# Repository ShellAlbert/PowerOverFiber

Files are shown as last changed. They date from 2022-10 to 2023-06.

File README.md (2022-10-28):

# PowerOverFiber
Video Monitor Low Power Consumption Project   
TinyUARTCamera - STM32L496RGT6 LQFP-64   
SerialCamera - STM32L496ZGT6 LQFP-144    

# October 25, 2022   
InfraredCamera - iRay Infrared Camera LVCMOS 14-bits Gray image output.   
STM32L496ZGT6 LQFP-144 + PSRAM 32Mbits   
For single infrared image, the size is 640*512*16bits=5Mbits.    
STM32 FSMC Memory mapping    
Bank1: 4*64Mbyte    
Since we use CE1 in design, so the address range is 0x6000,0000~0x603F,FFFF   

We have IS66WVE2M16EBLL-70BLI-TR PSRAM on board, it has 21 bits address and 16 bits data bus, so 2^21*16bits=32Mbits.

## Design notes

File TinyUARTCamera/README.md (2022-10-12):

# TinyUARTCamera
MCU: STM32L496RGT6   
Camera: OV2640   
IDE: STM32CubeIDE_1.10.1 + STM32CubeL4 FW 1.17.2

First working version 
October 12, 2022 by Shell Albert   

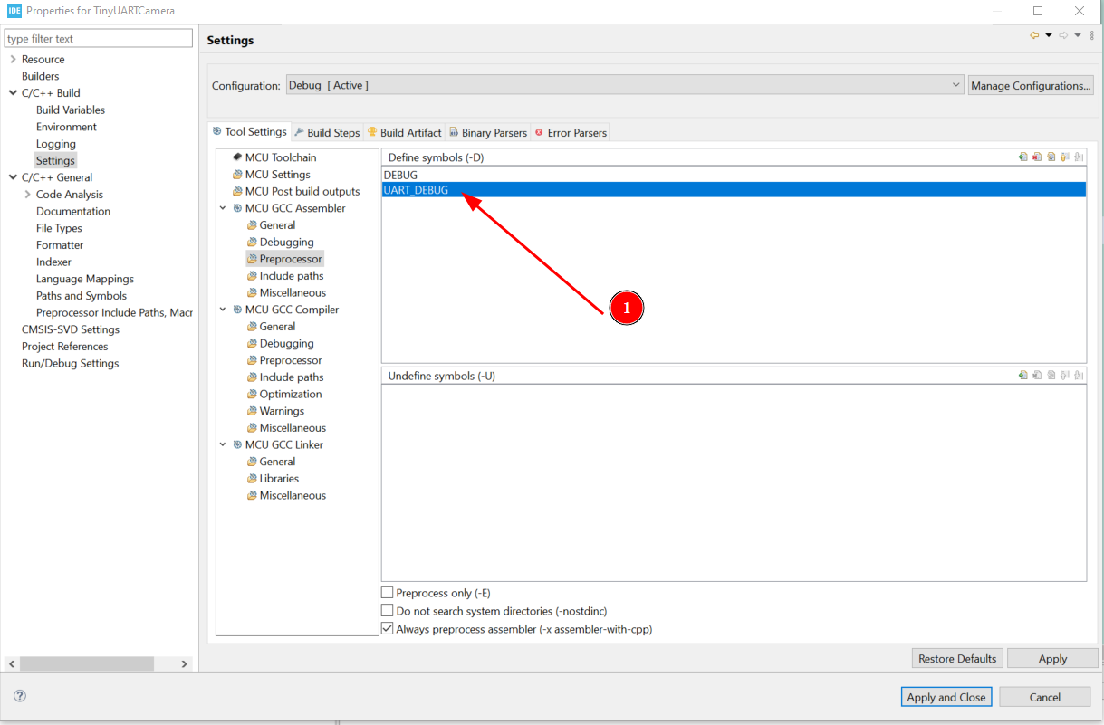
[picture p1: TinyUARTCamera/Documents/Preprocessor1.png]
Preprocessor1
   
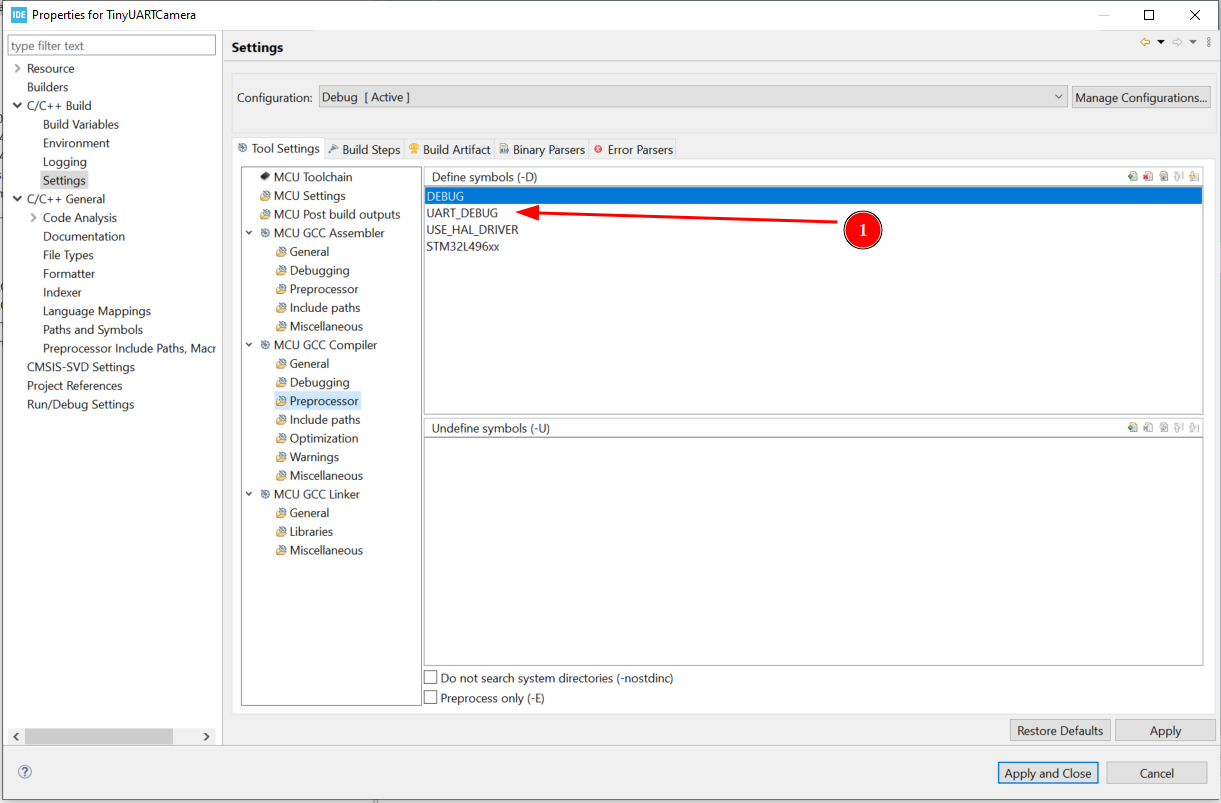
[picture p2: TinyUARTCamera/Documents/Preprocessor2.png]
Preprocessor2
   
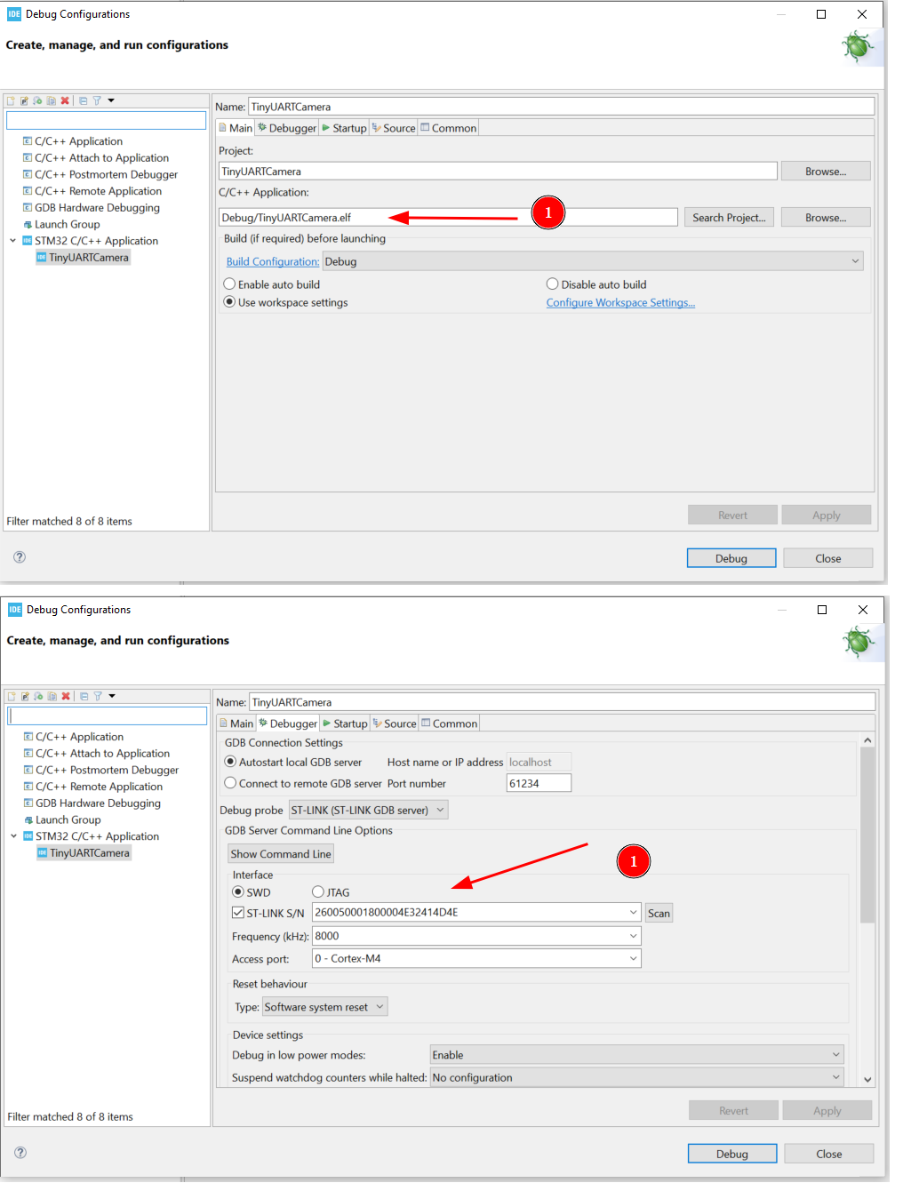
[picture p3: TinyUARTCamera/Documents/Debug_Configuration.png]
Debug_Configuration
   
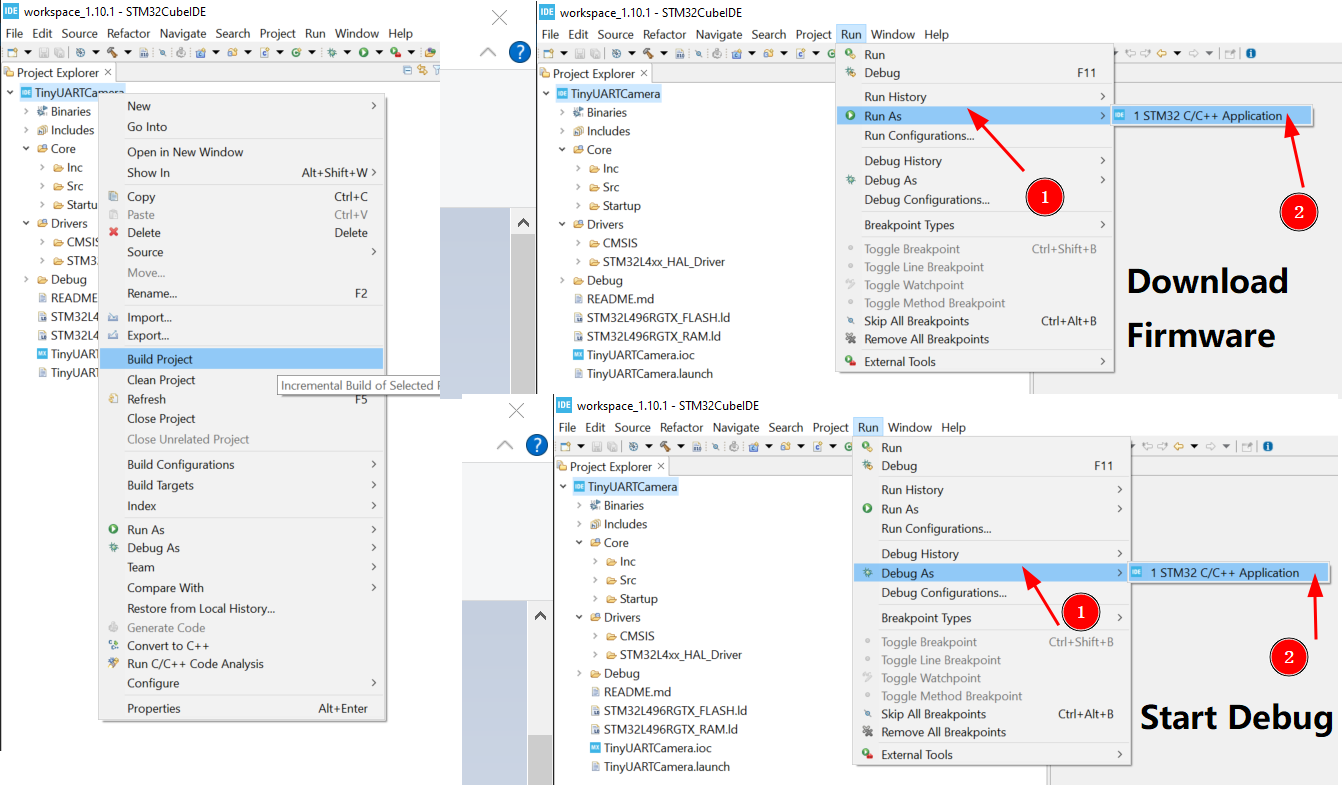
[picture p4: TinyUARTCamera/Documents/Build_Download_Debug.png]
Build_Download_Debug
   
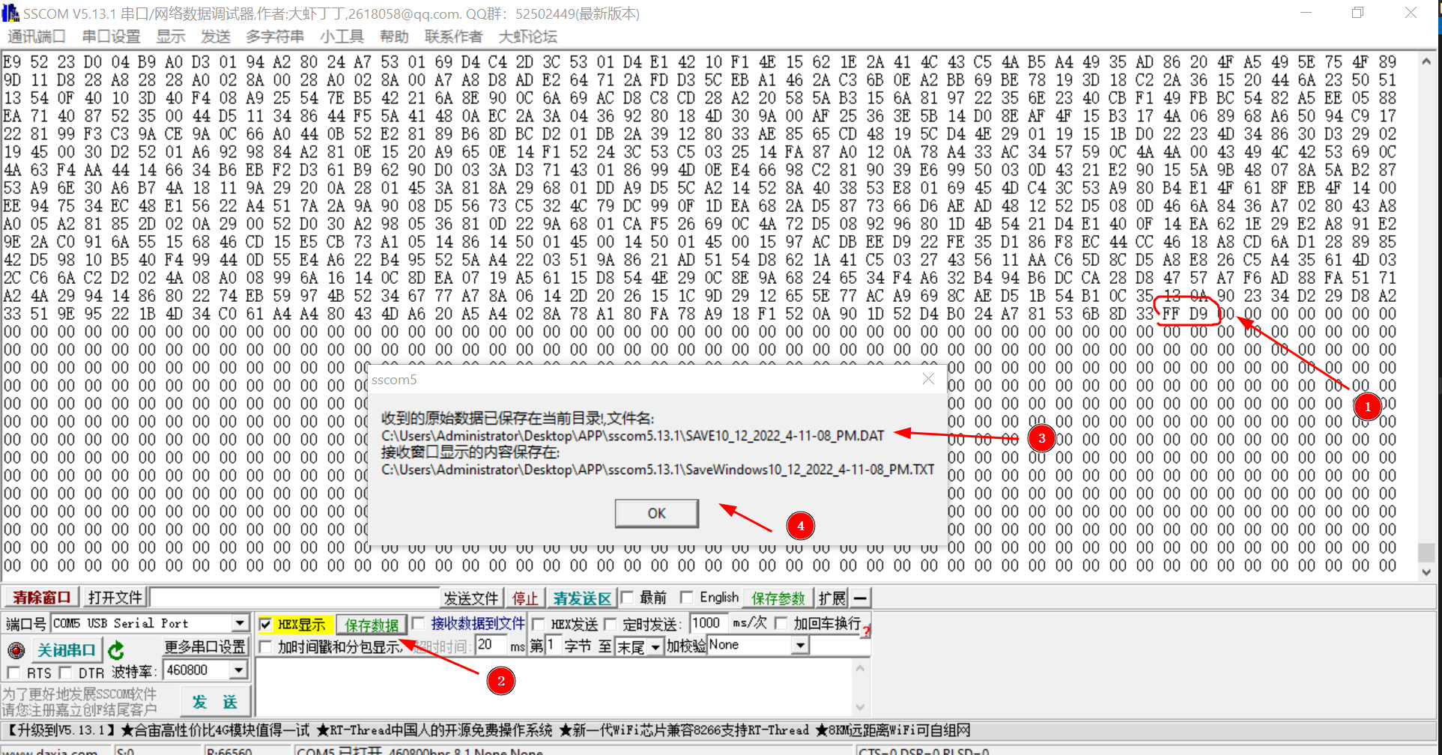
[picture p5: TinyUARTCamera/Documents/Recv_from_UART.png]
Recv_From_UART
   
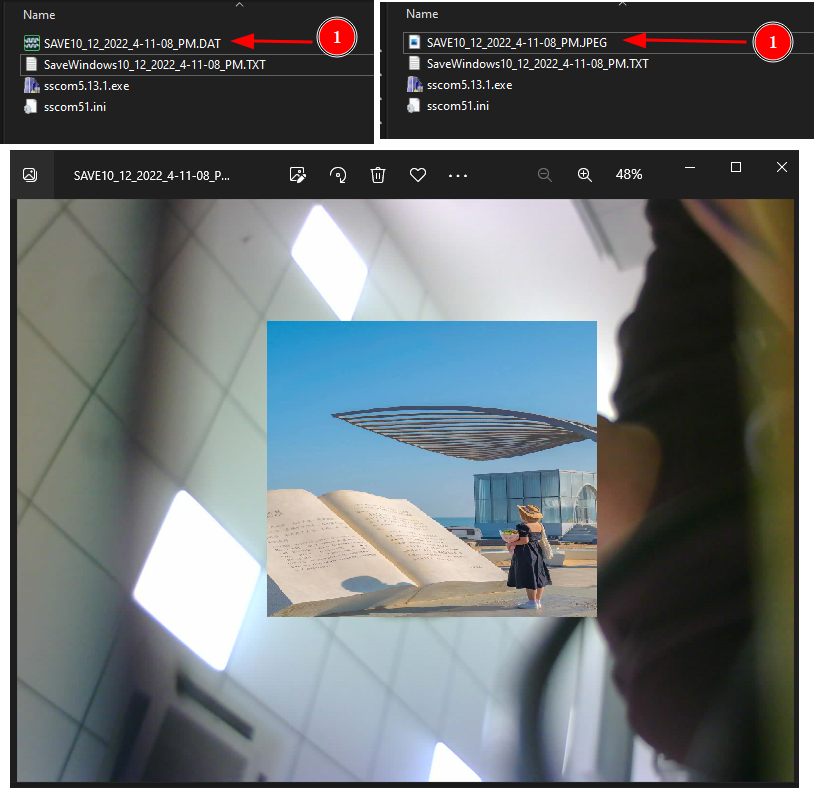
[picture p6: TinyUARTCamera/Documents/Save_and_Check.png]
Save_and_Check


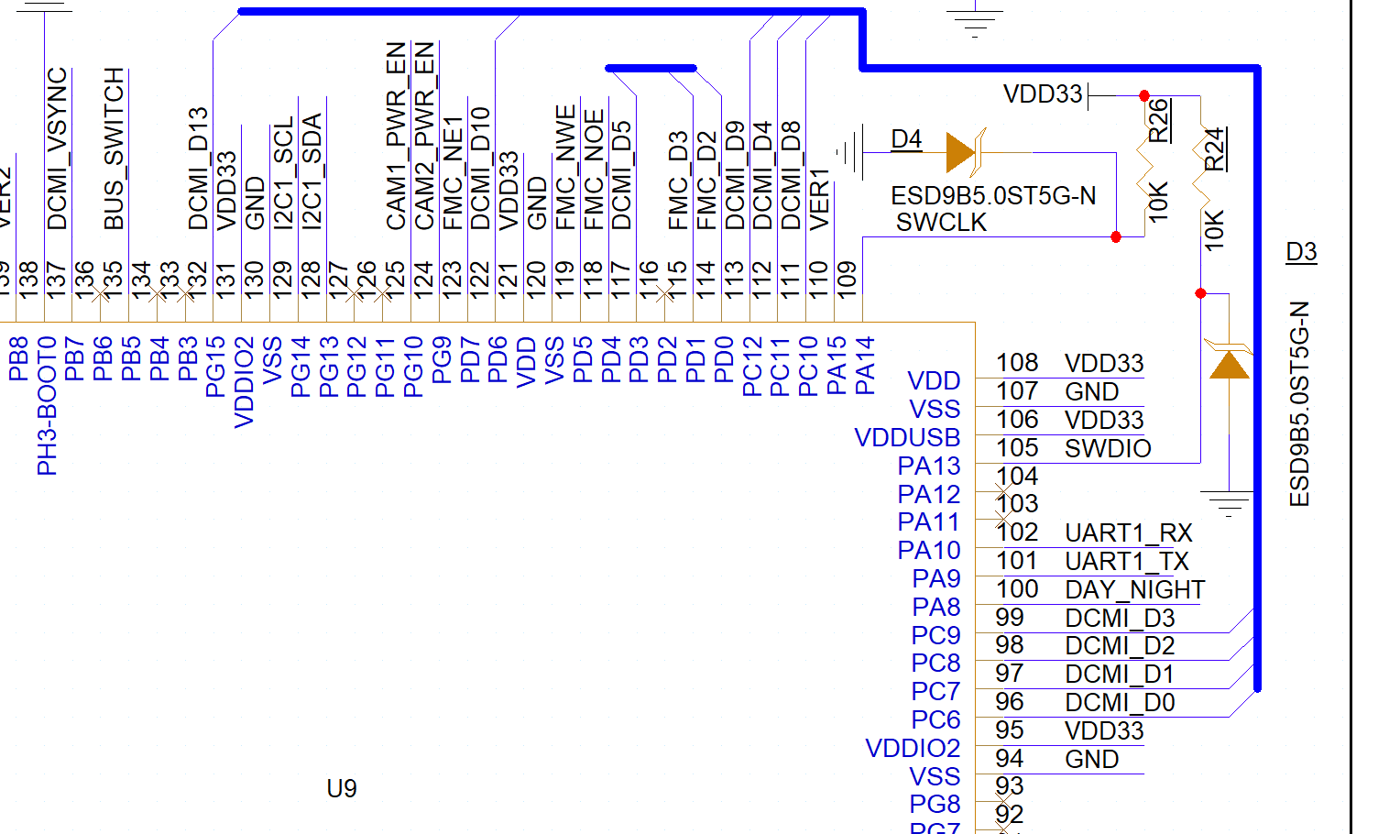
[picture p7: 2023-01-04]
Schematic/SERIALCAMERA.png

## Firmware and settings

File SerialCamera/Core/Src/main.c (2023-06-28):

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
/* Includes ------------------------------------------------------------------*/
#include "main.h"

/* USER CODE BEGIN Includes */
#include <string.h>
#include <stdio.h>
#include <stdarg.h>
#include "ov2640.h"
#include "Zsy_iRaySensor.h"
/* USER CODE END Includes */

/* USER CODE BEGIN PTD */
//#define ZDBG_MSG_EN 1
/* USER CODE END PTD */

DCMI_HandleTypeDef hdcmi;
DMA_HandleTypeDef hdma_dcmi;

I2C_HandleTypeDef hi2c1;
I2C_HandleTypeDef hi2c2;

TIM_HandleTypeDef htim1;

UART_HandleTypeDef huart1;
UART_HandleTypeDef huart2;
UART_HandleTypeDef huart3;

SRAM_HandleTypeDef hsram1;

/* USER CODE BEGIN PV */
static void
MX_DCMI_Init_OV2640 (void);
/* USER CODE END PV */

void SystemClock_Config(void);
static void MX_GPIO_Init(void);
static void MX_DMA_Init(void);
static void MX_DCMI_Init(void);
static void MX_I2C1_Init(void);
static void MX_I2C2_Init(void);
static void MX_TIM1_Init(void);
static void MX_USART1_UART_Init(void);
static void MX_USART2_UART_Init(void);
static void MX_USART3_UART_Init(void);
static void MX_FMC_Init(void);
/* USER CODE BEGIN PFP */
/* USER CODE BEGIN 0 */
/* USER CODE END PFP */


//the maximum linear address space is 65535 in word unit (32bits) for DMA.
//If the image size in words does not exceed 65535, the stream can be configured in normal mode.
//In general, one frame of JPEG compressed image can be 50KBytes~80KBytes.
//So here we use a 128KByte buffer.
#define JPEG_BUFFER_SIZE  (1024*31)  //128KB buffer size= 1024*31 INT bytes.
uint32_t iJpegBufferSize = JPEG_BUFFER_SIZE; //1024*128.
//SoC RAM.
//if we define this array as uint8_t, it will be failed. why?
//uint32_t iJpegBuffer[JPEG_BUFFER_SIZE];

//External RAM.
//Since DMA DONOT support write External RAM directly,
//so we must use DMA interrupt to copy data from SoC RAM to External RAM.
uint32_t iJpegBuffer[JPEG_BUFFER_SIZE] __attribute__ ((section(".ExtRAM")));
uint32_t iITFrameCnt = 0;
uint8_t g_iFSMFlag = 0;

/* frame buffer for infrared image buffer */
/* Yantai iRay Infrared Camera : 14-bit one pixel, resolution is 614*512 */
/* So 640*152*16bit/8bit= 655360bytes, /4bytes, sizeof(int)=163840 INT(32bits) */
/* 163840 Exceed 65535 !!!!!*/
#define INFRARED_IMGBUF_INT		163840 //(640*512*16/8/4)
uint32_t frameBufferExt[INFRARED_IMGBUF_INT] __attribute__ ((section(".ExtRAM")));

//SoC RAM Frame Buffer.
//640*512*16-bits
//640/2=320,512/2=256.
//The size of 1/4 part of image is calculated by 320*256*16-bits/8-bits=163840bytes,/4bytes=40960words.
#define SIZE_1_OF_4_WORD	(40960)
uint32_t frameBufferSoC[SIZE_1_OF_4_WORD + 128];

void
vprint (const char *fmt, va_list argp)
{
  char string[128];
  if (0 < vsprintf (string, fmt, argp)) // build string
    {
      // send message via UART3
      HAL_UART_Transmit (&huart3, (uint8_t*) string, strlen (string), 0xFFFF);
    }
}

void
ZUART_Printf (const char *fmt, ...) // custom printf() function
{
#ifdef ZDBG_MSG_EN
  va_list argp;
  va_start(argp, fmt);
  vprint (fmt, argp);
  va_end(argp);
#endif
}
/* USER CODE END 0 */

/**
  * @brief  The application entry point.
  * @retval int
  */
int main(void)
{
  /* USER CODE BEGIN 1 */
  char msg_buffer[128];
  uint32_t i;
  /* USER CODE END 1 */

  /* MCU Configuration--------------------------------------------------------*/

  /* Reset of all peripherals, Initializes the Flash interface and the Systick. */
  HAL_Init();

  /* Configure the system clock */
  SystemClock_Config();

  /* USER CODE BEGIN SysInit */

  //make sure MX_DCMI_Init() must be called after MX_DMA_Init().
  //make sure USART1_Init() must be called before GPIO_Init()
  //to avoid receive 00 at other side.
  /* USER CODE END SysInit */

  /* Initialize all configured peripherals */
  //MX_USART1_UART_Init();
  MX_USART2_UART_Init();
  //MX_USART3_UART_Init();
  MX_GPIO_Init();
  MX_DMA_Init();
  MX_DCMI_Init();
  MX_I2C1_Init();
  MX_I2C2_Init();
  //MX_TIM1_Init();
  //MX_FMC_Init();
  /* USER CODE BEGIN 2 */
  //ZUART_Printf("SerialCAM built on %s %s\r\n", __DATE__, __TIME__);
  /* External SRAM write-read test successfully!*/
#if 0
  //clear RAM to zero.
  for (i = 0; i < INFRARED_IMGBUF_INT; i++)
    {
      *(frameBufferExt + i) = 0;
    }
  //write data.
  for (i = 0; i < INFRARED_IMGBUF_INT; i++)
    {
      *(frameBufferExt + i) = i + 3;
    }
  //Read back and check data.
  for (i = 0; i < INFRARED_IMGBUF_INT; i++)
    {
      if ((i + 3) != frameBufferExt[i])
	{
	  sprintf (msg_buffer, "External RAM Test Error, %d!=%d, Code break down!\r\n", i + 3, frameBufferExt[i]);
	  HAL_UART_Transmit (&huart3, (uint8_t*) msg_buffer, strlen (msg_buffer), 200);
	  while (1)
	    {
	      //LED1 & LED2 OFF.
	      HAL_GPIO_WritePin (GPIOF, LED1_Pin | LED2_Pin, GPIO_PIN_RESET);
	      HAL_Delay (250);

	      //LED1 & LED2 ON.
	      HAL_GPIO_WritePin (GPIOF, LED1_Pin | LED2_Pin, GPIO_PIN_SET);
	      HAL_Delay (250);
	    }
	}
    }
#ifdef ZDBG_MSG_EN
  sprintf (msg_buffer, "External RAM Test Passed!\r\n");
  HAL_UART_Transmit (&huart3, (uint8_t*) msg_buffer, strlen (msg_buffer), 200);
#endif
#endif
  //Two LEDs OFF.
  HAL_GPIO_WritePin (GPIOF, LED1_Pin | LED2_Pin, GPIO_PIN_SET);

  //read DAY_NIGHT signal.
  //HAL_Delay (50);
  //if (HAL_GPIO_ReadPin (DAY_NIGHT_GPIO_Port, DAY_NIGHT_Pin))
  if (1)
    {
      //ZUART_Printf("Day - Visible\r\n");
      MX_DCMI_Init_OV2640 ();

      //Enable CAM1 power.
      HAL_GPIO_WritePin (GPIOG, CAM1_PWR_EN_Pin, GPIO_PIN_SET);
      //SYNC_SWITCH=0, CAM1 Signal Pass.
      //BUS_SWITCH=0, CAM1 Signal Pass.
      HAL_GPIO_WritePin (GPIOB, SYNC_SWITCH_Pin | BUS_SWITCH_Pin, GPIO_PIN_RESET);
      HAL_Delay (10);

      //Initial OV2640 registers via I2C.
      OV2640_Init (&hi2c1, &hdcmi);
      //must delay X seconds to bypass white-balance images to get normal images.
      HAL_Delay (3000);
      //OV2640_ResolutionOptions (imgRes);
      //HAL_Delay (10);

      /* Disable unwanted HSYNC (IT_LINE) / VSYNC (IT_VSYNC) interrupts */
      __HAL_DCMI_DISABLE_IT(&hdcmi, DCMI_IT_LINE | DCMI_IT_VSYNC|DCMI_IT_ERR|DCMI_IT_OVR);
      __HAL_DCMI_ENABLE_IT(&hdcmi, DCMI_IT_FRAME);

      while (1)
	{
	  uint8_t *pJpegData = (uint8_t*) (frameBufferSoC);
	  uint8_t iHeadFound = 0;
	  uint8_t iTailFound = 0;
	  uint32_t iValidEndPosition = 0;
	  int recv_len;
	  switch (g_iFSMFlag)
	    {
	    case 0:
	      //ZUART_Printf ("1-Start DMA\r\n");
	      //memset (frameBufferSoC, 0, SIZE_1_OF_4_WORD * 4);
	      //LED1 on.
	      //HAL_GPIO_WritePin (GPIOF, LED1_Pin, GPIO_PIN_RESET);
	      HAL_DCMI_Start_DMA (&hdcmi, DCMI_MODE_SNAPSHOT, (uint32_t) frameBufferSoC, SIZE_1_OF_4_WORD);
	      g_iFSMFlag = 1;
	      break;

	    case 1:
	      //ZUART_Printf("2-Waiting IT_FRAME...\r\n");
	      //HAL_Delay (100);
	      break;

	    case 2:
	      //ZUART_Printf("3-Get FRAME\r\n");
	      //Disable CAM1 power.
	      HAL_GPIO_WritePin (GPIOG, CAM1_PWR_EN_Pin, GPIO_PIN_RESET);
	      g_iFSMFlag = 3;
	      break;

	    case 3:
	      recv_len = SIZE_1_OF_4_WORD - __HAL_DMA_GET_COUNTER(hdcmi.DMA_Handle);
	      //ZUART_Printf("4-Get IT_FRAME %d,DMA %d\r\n", iITFrameCnt, recv_len);

	      //dump first 10 bytes data to UART3.
	      //ZUART_Printf("DATA-%08x-%08x\r\n", frameBufferSoC[0], frameBufferSoC[1]);

	      //frame head FF D8, frame end FF D9.
	      //loop to find the frame end to skip the last ZEROs.
	      for (i = 0; i < recv_len * 4; i++)
		{
		  if (pJpegData[i + 0] == 0xFF && pJpegData[i + 1] == 0xD8)
		    {
		      iHeadFound = 1;
		      break;
		    }
		}
	      for (i = recv_len * 4; i > 0; i--)
		{
		  if (pJpegData[i - 1] == 0xD9 && pJpegData[i - 2] == 0xFF)
		    {
		      uint32_t bypass = recv_len * 4 - i;
		      iTailFound = 1;
		      iValidEndPosition = recv_len * 4 - bypass;
		      break;
		    }
		}

	      //dump all data to UART2, transmit via Laser Diode.
	      if (iHeadFound && iTailFound)
		{
		  //Laser Diode Power up before Transmitting.
		  //0 = Laser Diode Power ON.
		  //1 = Laser Diode Power OFF.
		  HAL_GPIO_WritePin (LD_PWR_EN_GPIO_Port, LD_PWR_EN_Pin, GPIO_PIN_RESET);
		  HAL_Delay (5);

		  //Dump data to UART3 for debug.
		  //frame structure: package size+package data.
		  //HAL_UART_Transmit (&huart3, (uint8_t*) &iValidEndPosition, sizeof(iValidEndPosition) , 0xFFFFFFFF); //package size.
		  for (i = 0; i < iValidEndPosition; i++)
		    {
		      //UART2 is Laser Diode.
		      HAL_UART_Transmit (&huart2, (uint8_t*) &pJpegData[i], 1, 0xFFFFFFFF);
		      //UART3 is Debug Message Output.
		      //HAL_UART_Transmit (&huart3, (uint8_t*) &pJpegData[i], 1, 0xFFFFFFFF); //package data.
		    }
		  //Laser Diode Power down to save energy.
		  //0 = Laser Diode Power ON.
		  //1 = Laser Diode Power OFF.
		  HAL_GPIO_WritePin (LD_PWR_EN_GPIO_Port, LD_PWR_EN_Pin, GPIO_PIN_SET);
		}
	      g_iFSMFlag = 4;
	      break;

	    case 4:
	      if (1)
		{
		  //Configuration register pointer=0x02, 16-bits.
		  //0x1000: bit[12]=1, Temperature and Humidity are acquired in sequence, Temperature First.
		  uint8_t HDC_config[3] =
		    { 0x02, 0x10, 0x00 };
		  uint8_t HDC_trig = 0x00;
		  uint8_t HDC_data[4];
		  float temperature, humidity;
		  uint32_t tmpData;
		  uint32_t dataSize;

		  //initial I2C Slave.
		  HAL_I2C_Master_Transmit (&hi2c2, 0x80, HDC_config, 3, 0xFFFFFFFF);

		  //Trigger the measurements by executing a pointer write transaction with the address pointer set to 0x00.
		  HAL_I2C_Master_Transmit (&hi2c2, 0x80, &HDC_trig, 1, 0xFFFFFFFF);

		  //Wait for the measurements to complete.
		  while (HAL_GPIO_ReadPin (HT_DRDYn_GPIO_Port, HT_DRDYn_Pin) == 1)
		    {
		    }
		  //receive data.
		  HAL_I2C_Master_Receive (&hi2c2, 0x80, HDC_data, 4, 0xFFFFFFFF);

		  //Laser Diode Power up before Transmitting.
		  //0 = Laser Diode Power ON.
		  //1 = Laser Diode Power OFF.
		  HAL_GPIO_WritePin (LD_PWR_EN_GPIO_Port, LD_PWR_EN_Pin, GPIO_PIN_RESET);
		  HAL_Delay (5);

		  //dump all data to UART2, transmit via Laser Diode.
		  HAL_UART_Transmit (&huart2, HDC_data, 4, 0xFFFFFFFF);

		  //Laser Diode Power down to save energy.
		  //0 = Laser Diode Power ON.
		  //1 = Laser Diode Power OFF.
		  HAL_GPIO_WritePin (LD_PWR_EN_GPIO_Port, LD_PWR_EN_Pin, GPIO_PIN_SET);

		  //dump data to UART3, frame structure: package size+package data.
//		  dataSize=4;  //package size=4 bytes.
//		  HAL_UART_Transmit (&huart3, (const uint8_t*)&dataSize, 4, 0xffffffff);
//		  //package data.
//		  HAL_UART_Transmit (&huart3, HDC_data, 4, 0xffffffff);
#if 0 //Disable to Save Energy.
		  //ZUART_Printf("T: %02x%02x H:%02x%02x\r\n", HDC_data[0], HDC_data[1], HDC_data[2], HDC_data[3]);
		  tmpData = (uint32_t) HDC_data[0] << 8 | HDC_data[1];
		  temperature = tmpData / 65536.0;
		  temperature = temperature * 165.0f - 40.0f;
		  tmpData = (uint32_t) HDC_data[2] << 8 | HDC_data[3];
		  humidity = tmpData / 65536.0 * 100.0;
		  //ZUART_Printf ("Temperature:%.2f, Humidity:%.2f%%\r\n", temperature, humidity);
#endif
		  //LED1 off.
		  //HAL_GPIO_WritePin (GPIOF, LED1_Pin, GPIO_PIN_SET);
		}
	      //ZUART_Printf ("5-Done\r\n");
	      //HAL_PWR_EnterSTANDBYMode();
	      //dead loop to consume power till voltage drops down below 2.489V to reset MCU.
	      while (1)
		{
		  HAL_GPIO_WritePin (GPIOF, LED1_Pin, GPIO_PIN_RESET);
		  HAL_Delay (100);
		  HAL_GPIO_WritePin (GPIOF, LED1_Pin, GPIO_PIN_SET);
		  HAL_Delay (100);
		}
	      g_iFSMFlag = 0;
	      HAL_Delay(5000);
	      break;

	    default:
	      g_iFSMFlag = 0;
	      break;
	    }
	}
    }
  else
    {
      uint32_t i;
      uint8_t iPieces = 0;

      ZUART_Printf ("Night - Infrared\r\n");

      //Enable CAM2 Power.
      HAL_GPIO_WritePin (GPIOG, CAM2_PWR_EN_Pin, GPIO_PIN_SET);
      HAL_Delay (6000);

      //SYNC_SWITCH=1, CAM2 Signal Pass.
      //BUS_SWITCH=1, CAM2 Signal Pass.
      HAL_GPIO_WritePin (GPIOB, SYNC_SWITCH_Pin | BUS_SWITCH_Pin, GPIO_PIN_SET);
      HAL_Delay (500);

      //Set more than Once to ensure command was received successfully by Infrared Sensor.
      for (i = 0; i < 2; i++)
	{
	  uint8_t rxData[32];

	  //read FPA temperature.
	  uint8_t cmd_FPA_Temperature[] =
	    { 0xAA, 0x04, 0x01, 0xC3, 0x00, 0x72, 0xEB, 0xAA };

	  //read Chip Temperature.
	  uint8_t cmd_Chip_Temperature[] =
	    { 0xAA, 0x04, 0x01, 0x7C, 0x00, 0x2B, 0xEB, 0xAA };

	  //set LVCMOS interface.
	  uint8_t cmd_LVCMOS[] =
	    { 0xAA, 0x06, 0x01, 0x5D, 0x02, 0x02, 0x00, 0x12, 0xEB, 0xAA };

	  //Digital Video Source Selection=NUC, 14-bits.
	  uint8_t cmd_NUCSource[] =
	    { 0xAA, 0x05, 0x01, 0x5C, 0x01, 0x01, 0x0E, 0xEB, 0xAA };

	  //Digital Video Source Selection=DRC, 8-bits.
	  uint8_t cmd_DRCSource[] =
	    { 0xAA, 0x05, 0x01, 0x5C, 0x01, 0x02, 0x0F, 0xEB, 0xAA };

	  //Stop NUC.
	  uint8_t cmd_NUCStop[] =
	    { 0xAA, 0x05, 0x01, 0x01, 0x01, 0x00, 0xB2, 0xEB, 0xAA };

	  //LED2 on.
	  HAL_GPIO_WritePin (GPIOF, LED2_Pin, GPIO_PIN_RESET);
	  //read FPA Temperature.
	  if (HAL_UART_Transmit (&huart1, (uint8_t*) cmd_FPA_Temperature, sizeof(cmd_FPA_Temperature), 200) == HAL_OK)
	    {
	      memset (rxData, 0, sizeof(rxData));
	      //block rx with 200ms.
	      HAL_UART_Receive (&huart1, rxData, sizeof(rxData), 200);
	      ZUART_Printf ("FPA_Temperature: %02x %02x %02x %02x %02x %02x %02x %02x %02x %02x \r\n", ///<
		  rxData[0], rxData[1], rxData[2], rxData[3], rxData[4], ///<
		  rxData[5], rxData[6], rxData[7], rxData[8], rxData[9]);
	      HAL_Delay (100);
	    }

	  //read Chip Temperature.
	  if (HAL_UART_Transmit (&huart1, (uint8_t*) cmd_Chip_Temperature, sizeof(cmd_Chip_Temperature), 200) == HAL_OK)
	    {
	      memset (rxData, 0, sizeof(rxData));
	      //block rx with 200ms.
	      HAL_UART_Receive (&huart1, rxData, sizeof(rxData), 200);
	      ZUART_Printf ("Chip_Temperature: %02x %02x %02x %02x %02x %02x %02x %02x %02x %02x \r\n", ///<
		  rxData[0], rxData[1], rxData[2], rxData[3], rxData[4], ///<
		  rxData[5], rxData[6], rxData[7], rxData[8], rxData[9]);
	      HAL_Delay (100);
	    }

	  //select NUC as Digital Video Source.
	  if (HAL_UART_Transmit (&huart1, (uint8_t*) cmd_NUCSource, sizeof(cmd_NUCSource), 200) == HAL_OK)
	  //if (HAL_UART_Transmit (&huart1, (uint8_t*) cmd_DRCSource, sizeof(cmd_DRCSource), 200) == HAL_OK)
	    {
	      memset (rxData, 0, sizeof(rxData));
	      //block rx with 200ms.
	      HAL_UART_Receive (&huart1, rxData, sizeof(rxData), 200);
	      ZUART_Printf ("dvSource: %02x %02x %02x %02x %02x %02x %02x %02x %02x %02x \r\n", ///<
		  rxData[0], rxData[1], rxData[2], rxData[3], rxData[4], ///<
		  rxData[5], rxData[6], rxData[7], rxData[8], rxData[9]);
	      HAL_Delay (100);
	    }

	  //set LVCMOS interface.
	  if (HAL_UART_Transmit (&huart1, (uint8_t*) cmd_LVCMOS, sizeof(cmd_LVCMOS), 200) == HAL_OK)
	    {
	      memset (rxData, 0, sizeof(rxData));
	      //block rx with 200ms.
	      HAL_UART_Receive (&huart1, rxData, sizeof(rxData), 200);
	      ZUART_Printf ("LVCMOS: %02x %02x %02x %02x %02x %02x %02x %02x %02x %02x \r\n", ///<
		  rxData[0], rxData[1], rxData[2], rxData[3], rxData[4], ///<
		  rxData[5], rxData[6], rxData[7], rxData[8], rxData[9]);
	      HAL_Delay (100);
	    }

	  //set NUC calibration.
	  if (HAL_UART_Transmit (&huart1, (uint8_t*) cmd_NUCStop, sizeof(cmd_NUCStop), 200) == HAL_OK)
	    {
	      memset (rxData, 0, sizeof(rxData));
	      //block rx with 200ms.
	      HAL_UART_Receive (&huart1, rxData, sizeof(rxData), 200);
	      ZUART_Printf ("NUC_Stop: %02x %02x %02x %02x %02x %02x %02x %02x %02x %02x \r\n", ///<
		  rxData[0], rxData[1], rxData[2], rxData[3], rxData[4], ///<
		  rxData[5], rxData[6], rxData[7], rxData[8], rxData[9]);
	      HAL_Delay (100);
	    }

	  //LED2 off.
	  HAL_GPIO_WritePin (GPIOF, LED2_Pin, GPIO_PIN_SET);
	  HAL_Delay (200);
	}
      /* Disable unwanted HSYNC (IT_LINE) / VSYNC (IT_VSYNC) interrupts */
      __HAL_DCMI_DISABLE_IT(&hdcmi, DCMI_IT_LINE | DCMI_IT_VSYNC|DCMI_IT_ERR|DCMI_IT_OVR);
      __HAL_DCMI_ENABLE_IT(&hdcmi, DCMI_IT_FRAME|DCMI_IT_ERR);

      while (1)
	{
	  int remain_len;
	  int recv_len;
	  switch (g_iFSMFlag)
	    {
	    case 0:
	      ZUART_Printf ("1-Start DMA\r\n");
	      // 65535 (0xFFFF is the DMA maximum transfer length).
	      //(640*512*16bits)/8bits=655360bytes=//4bytes(int)=163840(int)
	      //163840(int)/65535(int)=2.5 times.
	      //163840/4=40960 << 65535
	      //Since DMA is in Circle mode, so it can not generate Complete Interrupt.
	      //But we can use Frame Interrupt.
	      // HAL_DCMI_Start_DMA (&hdcmi, DCMI_MODE_SNAPSHOT, (uint32_t) frameBufferInfrared, 40960/*INFRARED_IMGBUF_INT*/);

	      //why can't DMA store data to External RAM?
	      //if change to SoC RAM, we can get IT_FRAME interrupt!
	      //why?????
	      //HAL_DCMI_Start_DMA (&hdcmi, DCMI_MODE_SNAPSHOT, (uint32_t) frameBufferInfrared, 1024*64);

	      /*
	       * @param  DCMI_Mode DCMI capture mode snapshot or continuous grab.
	       * @param  pData     The destination memory buffer address.
	       * @param  Length    The length of capture to be transferred (in 32-bit words).
	       * @note  In case of length larger than 65535 (0xFFFF is the DMA maximum transfer length),
	       *        the API uses the end of the destination buffer as a work area: HAL_DCMI_Start_DMA()
	       *        initiates a circular DMA transfer from DCMI DR to the ad-hoc work buffer and each
	       *        half and complete transfer interrupt triggers a copy from the work buffer to
	       *        the final destination pData through a second DMA channel.
	       */
	      memset (frameBufferSoC, 0, sizeof(frameBufferSoC));
	      //okay, we can get data from Infrared Sensor.
	      //HAL_DCMI_Start_DMA (&hdcmi, DCMI_MODE_SNAPSHOT, (uint32_t) frameBufferSoC, 1024*64/2);
	      //HAL_DCMI_Start_DMA (&hdcmi, DCMI_MODE_SNAPSHOT, (uint32_t) frameBufferSoC, 65535);

	      //Since we have no enough SoC RAM to hold one complete frame,
	      //so we use crop features to cut one frame into 4 pieces.
	      //We get 1/4 part each time and after 4 times, we get one complete frame.
	      //First, we store 1/4 part data into SoC RAM, then we move them into External RAM to generate a complete frame.
	      //640*512*16-bits
	      //640/2=320,512/2=256
	      //So, cut into 4 pieces, one part size = 320*256*16-bits/8-bits=163840bytes,/4bytes=40960(words)

	      //X0: DCMI window crop window X offset (number of pixels clocks to count before the capture).
	      //HOFFCNT[13:0]: Horizontal offset count
	      //This value gives the number of pixel clocks to count before starting a capture.

	      //Y0: DCMI window crop window Y offset (image capture starts with this line number, previous line data are ignored).
	      //VST[12:0]: Vertical start line count
	      //The image capture starts with this line number. Previous line data are ignored.

	      //XSize DCMI crop window horizontal size (in number of pixels per line).
	      //CAPCNT[13:0]: Capture count
	      //This value gives the number of pixel clocks to be captured from the starting point on the same line.
	      //It value must corresponds to word-aligned data for different widths of parallel interfaces.
	      //0x0000 => 1 pixel
	      //0x0001 => 2 pixels
	      //0x0002 => 3 pixels

	      //YSize DCMI crop window vertical size (in lines count).
	      //VLINE[13:0]: Vertical line count
	      //This value gives the number of lines to be captured from the starting point.
	      //0x0000: 1 line
	      //0x0001: 2 lines
	      //0x0002: 3 lines
	      //HAL_DCMI_ConfigCROP(&DCMIHandle, x*2, y, w*2-1, h-1);
	      switch (iPieces)
		{
		case 0: //(0,0)
		  HAL_DCMI_ConfigCrop (&hdcmi, 0, 0, 640 * 2 - 1, 128 - 1);
		  break;
		case 1: //(0,1)
		  HAL_DCMI_ConfigCrop (&hdcmi, 0, 128, 640 * 2 - 1, 128 - 1);
		  break;
		case 2: //(1,0)
		  HAL_DCMI_ConfigCrop (&hdcmi, 0, 256, 640 * 2 - 1, 128 - 1);
		  break;
		case 3: //(1,1)
		  HAL_DCMI_ConfigCrop (&hdcmi, 0, 384, 640 * 2 - 1, 128 - 1);
		  break;
		default:
		  HAL_DCMI_ConfigCrop (&hdcmi, 0, 0, 640 * 2 - 1, 128 - 1);
		  break;
		}
	      HAL_DCMI_EnableCrop (&hdcmi);
	      //the Frame Buffer Size must be a little greater than Expected Size.
	      //Otherwise __HAL_DMA_GET_COUNTER() will not return correct result!!!
	      HAL_DCMI_Start_DMA (&hdcmi, DCMI_MODE_SNAPSHOT, (uint32_t) frameBufferSoC, SIZE_1_OF_4_WORD + 128);

	      //error, why doesn't DMA store data to External RAM?
	      //Blocked at 2-Waiting IT_FRAME.
	      //HAL_DCMI_Start_DMA (&hdcmi, DCMI_MODE_SNAPSHOT, (uint32_t) frameBufferInfrared, 65535/*INFRARE_IMGBUF_INT*/);

	      //error, we get all 0x00 data from Infrared Sensor!!!!!!!!
	      //HAL_DCMI_Start_DMA (&hdcmi, DCMI_MODE_SNAPSHOT, (uint32_t) frameBufferSoC, 1024*64);

	      g_iFSMFlag = 1;
	      break;

	    case 1:
	      ZUART_Printf ("2-Waiting IT_FRAME...\r\n");
	      HAL_Delay (100);
	      break;

	    case 2:
	      ZUART_Printf ("3-Get FRAME\r\n");
	      g_iFSMFlag = 3;
	      break;

	    case 3:
	      remain_len = __HAL_DMA_GET_COUNTER(hdcmi.DMA_Handle);
	      recv_len = (SIZE_1_OF_4_WORD + 128) - remain_len;
	      ZUART_Printf ("4-Get IT_FRAME %d, DMA Transfered:%d\r\n", iITFrameCnt, recv_len);
	      //LED2 on.
	      HAL_GPIO_WritePin (GPIOF, LED2_Pin, GPIO_PIN_RESET);
	      //dump first 10 bytes data to UART3.
	      ZUART_Printf ("DATA-%08x-%08x\r\n", frameBufferSoC[0], frameBufferSoC[1]);
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

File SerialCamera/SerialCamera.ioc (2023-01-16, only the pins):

Mcu.UserName=STM32L496ZGTx
PA10.Signal=USART1_RX
PA2.Signal=USART2_TX
PA3.Signal=USART2_RX
PA4.Signal=DCMI_HSYNC
PA5.GPIO_Label=LD_PWR_EN
PA5.Signal=GPIO_Output
PA6.Signal=DCMI_PIXCLK
PA7.Signal=I2C3_SCL
PA8.GPIO_Label=DAY_NIGHT
PA8.Signal=GPIO_Input
PA9.Signal=USART1_TX
PB1.GPIO_Label=SYNC_SWITCH
PB1.Signal=GPIO_Output
PB10.Signal=I2C2_SCL
PB11.Signal=I2C2_SDA
PB12.GPIO_Label=HT_DRDYn
PB12.Signal=GPIO_Input
PB5.GPIO_Label=BUS_SWITCH
PB5.Signal=GPIO_Output
PB7.Signal=DCMI_VSYNC
PB8.GPIO_Label=VER2
PB8.Signal=GPIO_Input
PC1.GPIO_Label=CAM1_RST
PC1.Signal=GPIO_Output
PC10.Signal=DCMI_D8
PC11.Signal=DCMI_D4
PC12.Signal=DCMI_D9
PC4.Signal=USART3_TX
PC5.Signal=USART3_RX
PC6.Signal=DCMI_D0
PC7.Signal=DCMI_D1
PC8.Signal=DCMI_D2
PC9.Signal=DCMI_D3
PD0.Signal=FMC_D2_DA2
PD1.Signal=FMC_D3_DA3
PD10.Signal=FMC_D15_DA15
PD11.Signal=FMC_A16_CLE
PD12.Signal=FMC_A17_ALE
PD13.Signal=FMC_A18
PD14.Signal=FMC_D0_DA0
PD15.Signal=FMC_D1_DA1
PD3.Signal=DCMI_D5
PD4.Signal=FMC_NOE
PD5.Signal=FMC_NWE
PD6.Signal=DCMI_D10
PD7.Signal=FMC_NE1
PD8.Signal=FMC_D13_DA13
PD9.Signal=FMC_D14_DA14
PE0.Signal=FMC_NBL0
PE1.Signal=FMC_NBL1
PE10.Signal=FMC_D7_DA7
PE11.Signal=FMC_D8_DA8
PE12.Signal=FMC_D9_DA9
PE13.Signal=FMC_D10_DA10
PE14.Signal=FMC_D11_DA11
PE15.Signal=FMC_D12_DA12
PE3.Signal=FMC_A19
PE4.Signal=FMC_A20
PE5.Signal=DCMI_D6
PE6.Signal=DCMI_D7
PE7.Signal=FMC_D4_DA4
PE8.Signal=FMC_D5_DA5
PE9.Signal=FMC_D6_DA6
PF0.Signal=FMC_A0
PF1.Signal=FMC_A1
PF10.Signal=DCMI_D11
PF11.Signal=DCMI_D12
PF12.Signal=FMC_A6
PF13.Signal=FMC_A7
PF14.Signal=FMC_A8
PF15.Signal=FMC_A9
PF2.Signal=FMC_A2
PF3.Signal=FMC_A3
PF4.Signal=FMC_A4
PF5.Signal=FMC_A5
PF6.GPIO_Label=CAM1_PWDN
PF6.Signal=GPIO_Output
PF8.GPIO_Label=LED1
PF8.Signal=GPIO_Output
PF9.GPIO_Label=LED2
PF9.Signal=GPIO_Output
PG0.Signal=FMC_A10
PG1.Signal=FMC_A11
PG10.GPIO_Label=CAM1_PWR_EN
PG10.Signal=GPIO_Output
PG13.Signal=I2C1_SDA
PG14.Signal=I2C1_SCL
PG15.Signal=DCMI_D13
PG2.Signal=FMC_A12
PG3.Signal=FMC_A13
PG4.Signal=FMC_A14
PG5.Signal=FMC_A15
PG9.GPIO_Label=CAM2_PWR_EN
PG9.Signal=GPIO_Output

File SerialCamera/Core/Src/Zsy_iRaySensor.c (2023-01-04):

/*
 * Zsy_iRaySensor.c
 *
 *  Created on: Dec 13, 2022
 *      Author: Administrator
 */
#include "Zsy_iRaySensor.h"
#include "stm32l4xx_hal.h"
//115200bps, 8N1, LSB first.
//USART1 was connected on PCB Board.
extern UART_HandleTypeDef huart1;
void
Zsy_iRaySensorInit (void)
{
  //read FPA temperature.
  uint8_t cmd[] =
    { 0xaa, 0x04, 0x01, 0xc3, 0x00, 0x72, 0xeb, 0xaa };
  uint8_t rxData[32];
  //block tx with 5000ms.
  if(HAL_UART_Transmit (&huart1, (uint8_t*) cmd, sizeof(cmd), 5000)==HAL_OK)
    {
      //block rx with 2000ms.
      HAL_UART_Receive(&huart1, rxData, sizeof(rxData), 5000);
    }
  if(rxData[0]==0x55 && rxData[8]==0xAA)
    {

    }
}

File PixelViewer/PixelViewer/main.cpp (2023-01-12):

#include "zwidget.h"

#include <QApplication>
#include <QLocale>
#include <QTranslator>

int main(int argc, char *argv[])
{
    QApplication a(argc, argv);

    QTranslator translator;
    const QStringList uiLanguages = QLocale::system().uiLanguages();
    for (const QString &locale : uiLanguages) {
        const QString baseName = "PixelViewer_" + QLocale(locale).name();
        if (translator.load(":/i18n/" + baseName)) {
            a.installTranslator(&translator);
            break;
        }
    }
    Widget w;
    w.loadRAWData();
    w.show();
    return a.exec();
}

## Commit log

2022-10-12 first working version.
    The first working version for STM32L496RGT6 with STM32CubeIDE1.10.1.
2022-10-12 First working version.
    STM32L496ZGT6 LQFP144
    [SerialCamera Debug.cfg]
2022-10-15 Add External 32Mbits PSRAM.
    [SERIALCAMERA.DSN]
2022-10-17 update footprints of schematic.
    [SERIALCAMERA.DSN]
2022-10-19 Layout Circle Board.
    [PoFA1-1.brd, PoFA1-2.brd, PoFA1-3.brd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]
2022-10-20 PCB Layout in Progress
    [PoFA1-3.brd, PoFA1-4.brd, PoFA1-5.brd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]
2022-10-22 Add Delay tune.
    [PoFA1-1.brd, PoFA1-10.brd, PoFA1-11.brd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]
2022-10-28 External PSRAM Debug.
    [InfraredCamera Debug.cfg, PoFA1-11.brd, PoFA1-12.brd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]
2022-11-27 Circle PCB with OV2640 okay.
    [PoFA1-21.brd, SERIALCAMERA.DSN, art_param.txt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]
2023-01-04 SWD okay with Infrared Sensor connected, Rx Response from Sensor.
    [PoFA1-20.brd, SERIALCAMERA.DSN]
2023-01-04 Debug DCMI Interface.
    Two ESD caused can not connect to ST-Link V2, remove them, connected okay while Powering Infrared Sensor. UART1 configures Sensor to generate VSYNC,HSYNC,PCLK and 14-bits data. o far, I'm debugging D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
2023-01-05 All received data were ZERO.
    I wanna get part of the whole image data, 64KB, and the IT_Frame interrupt was triggered, but the received data are all zero. Could find what reason cause this.
2023-01-09 First time to get Data from Infrared Sensor.
    1-Start DMA
    2-Waiting IT_FRAME...
    3-Get FRAME
    4-Get IT_FRAME 36,DMA 32768
    DATA-0f570f52-0f500f57
    5-Done
2023-01-12 DCMI DMA Read iRay Infrared Sensor Successfully.
    The first version of get 1/4 part of one complete frame of iRay Infrared Sensor.
2023-01-13 Get Infrared Sensor data successfully but image is not correct.
    The best way to find what causes this is to use Test Pattern of Sensor. To force the sensor output fixed data, then we can check if we get the correct data as expected.
    [main.c]
2023-01-13 Yantai iRay Infrared Sensor Data Read Successfully.
2023-01-16 Read Temperature&Humidity Successfully.
2023-01-17 Add Data Structure of UART Protocol.
    JpegSize, JpegData, HTSize, HTData.
2023-01-31 40s to upload one frame.
2023-02-01 Initial Peripherals before IO to avoid UART send 00 at power up.
    [main.c]
2023-06-28 backup before re-installing windows.
    [PoFA1-21.brd]

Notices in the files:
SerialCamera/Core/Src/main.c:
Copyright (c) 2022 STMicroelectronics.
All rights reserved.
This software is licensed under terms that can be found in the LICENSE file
